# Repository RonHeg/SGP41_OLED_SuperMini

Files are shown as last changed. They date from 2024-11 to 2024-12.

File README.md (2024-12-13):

The Evs-2 SGP41 OLED SuperMini is a small PCB from RJ Hegler Technologies, LLC containing Temperature, Humidity, Pressure, VOC and NOx sensors designed to connect to the ESP32C3 SuperMini microcontroller. The PCB is also configurable to easily attach to a XIAO microcontroller or, 
with jumper wires, you could attach it to other processors.

The sensors are: Sensirion AG SHT-40-AD1B Temperature and Humidity. Sensirion AG SGP41-D-R4 NOx and VOC. TDK ICP-10111 Barometric pressure and temperature. The PCB uses its hosts 3.3v supply (~11mA with the pre-loaded software) and communicates via I2C.

EVs-2_SGP41_VOC.ino sends data thru the serial port at a baud rate of 115,200 and also displays 4 lines on a OLED display (if you are using a different display, please verify pinout, some OLED displays have Vcc and GND reversed).
The OLED display reads:

	SGP41 VOC Sensor
	78.23F, RH 48.00%
	NOx = 1, VOC = 94
	28.97inHg
 
(Numbers in the data are an example, your readings should be the actual for your conditions)

Example of data sent through the serial port is:

------------------------------

SHT40

T: 26.32        RH: 28.41

Tticks: 26704   RHticks: 18016

SGP41

compensationRh: 18016   compensationT: 26704

raw VOC Index: 28689    raw NOx Index: 0

VOC Index: 0    NOx Index: 0

ICP-10111

Temperature: 27.38C

99919.05Pa      29.51inHg

Altitude: 132.09m

------------------------------

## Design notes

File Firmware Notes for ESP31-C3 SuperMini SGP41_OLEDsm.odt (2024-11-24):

Firmware Notes

RJ Hegler Technologies, LLC

Project: SGP41_OLED_SuperMini

Processor: ESP32-C3 SuperMini or Seeed Studio XIAO ESP32C3 depending on resistor settings

Board: Nologo ESP32C3 Super Mini

Development Platform: Arduino 2.3.3

PC: Main

Path: C:\Users\Ron\Documents\Arduino\STM32G0Blink\Evs-2_SGP41_VOC\Evs_SGP41_VOC.ino

#include <Arduino.h>

/*

* I2C-Generator: 0.3.0

* Yaml Version: 0.1.0

* Template Version: 0.7.0-62-g3d691f9

*/

/*

*

* Portions Copyright (c) 2021, Sensirion AG

* All rights reserved.

*

* Redistribution and use in source and binary forms, with or without

* modification, are permitted provided that the following conditions are met:

*

* * Redistributions of source code must retain the above copyright notice, this

* list of conditions and the following disclaimer.

*

* * Redistributions in binary form must reproduce the above copyright notice,

* this list of conditions and the following disclaimer in the documentation

* and/or other materials provided with the distribution.

*

* * Neither the name of Sensirion AG nor the names of its

* contributors may be used to endorse or promote products derived from

* this software without specific prior written permission.

*

* THIS SOFTWARE IS PROVIDED BY THE COPYRIGHT HOLDERS AND CONTRIBUTORS "AS IS"

* AND ANY EXPRESS OR IMPLIED WARRANTIES, INCLUDING, BUT NOT LIMITED TO, THE

* IMPLIED WARRANTIES OF MERCHANTABILITY AND FITNESS FOR A PARTICULAR PURPOSE

* ARE DISCLAIMED. IN NO EVENT SHALL THE COPYRIGHT HOLDER OR CONTRIBUTORS BE

* LIABLE FOR ANY DIRECT, INDIRECT, INCIDENTAL, SPECIAL, EXEMPLARY, OR

* CONSEQUENTIAL DAMAGES (INCLUDING, BUT NOT LIMITED TO, PROCUREMENT OF

* SUBSTITUTE GOODS OR SERVICES; LOSS OF USE, DATA, OR PROFITS; OR BUSINESS

* INTERRUPTION) HOWEVER CAUSED AND ON ANY THEORY OF LIABILITY, WHETHER IN

* CONTRACT, STRICT LIABILITY, OR TORT (INCLUDING NEGLIGENCE OR OTHERWISE)

* ARISING IN ANY WAY OUT OF THE USE OF THIS SOFTWARE, EVEN IF ADVISED OF THE

* POSSIBILITY OF SUCH DAMAGE.

* Portions Copyright (c) 2024, RJ Hegler Technologies, LLC

* Other Copyright information can be found in the .h files listed below

*

* 11/21/24 RJH

*/

#include <Wire.h>

#include <NOxGasIndexAlgorithm.h>

#include <SensirionI2CSgp41.h>

#include <SensirionI2cSht4x.h>

#include <VOCGasIndexAlgorithm.h>

#include <DFRobot_ICP10111.h>

#include <U8g2lib.h>

U8G2_SSD1306_128X64_NONAME_F_HW_I2C u8g2(U8G2_R0, /* reset=*/ U8X8_PIN_NONE); //U8g2lib has 'drivers' for quite a few other displays

SensirionI2cSht4x sht4x; // original code had: SensirionI2CSht4x (capitol C)

SensirionI2CSgp41 sgp41;

DFRobot_ICP10111 icp;

VOCGasIndexAlgorithm voc_algorithm;

NOxGasIndexAlgorithm nox_algorithm;

// Time in seconds needed for NOx conditioning

// WARNING: To avoid damage to the sensing material the conditioning must not

// exceed 10s!

uint16_t conditioning_s = 10;

char errorMessage[64];

void setup() {

Serial.begin(115200);

Wire.begin();

sht4x.begin(Wire, 0x44); //original code did not have the I2C address

sgp41.begin(Wire);

u8g2.begin();

u8g2.enableUTF8Print();

u8g2.clearBuffer(); // clear the internal memory

u8g2.setFont(u8g2_font_7x14B_tf);

//u8g2.setFont(u8g2_font_t0_11_tf);

u8g2.drawStr(0,12, "SGP41 VOC Sensor");

u8g2.drawStr(0,28, "Initializing...");

u8g2.sendBuffer(); // transfer internal memory to the display

delay(1000);

int32_t index_offset;

int32_t learning_time_offset_hours;

int32_t learning_time_gain_hours;

int32_t gating_max_duration_minutes;

int32_t std_initial;

int32_t gain_factor;

voc_algorithm.get_tuning_parameters(

index_offset, learning_time_offset_hours, learning_time_gain_hours,

gating_max_duration_minutes, std_initial, gain_factor);

Serial.println("\nVOC Gas Index Algorithm parameters");

Serial.print("Index offset:\t");

Serial.println(index_offset);

Serial.print("Learing time offset hours:\t");

Serial.println(learning_time_offset_hours);

Serial.print("Learing time gain hours:\t");

Serial.println(learning_time_gain_hours);

Serial.print("Gating max duration minutes:\t");

Serial.println(gating_max_duration_minutes);

Serial.print("Std inital:\t");

Serial.println(std_initial);

Serial.print("Gain factor:\t");

Serial.println(gain_factor);

nox_algorithm.get_tuning_parameters(

index_offset, learning_time_offset_hours, learning_time_gain_hours,

gating_max_duration_minutes, std_initial, gain_factor);

Serial.println("\nNOx Gas Index Algorithm parameters");

Serial.print("Index offset:\t");

Serial.println(index_offset);

Serial.print("Learing time offset hours:\t");

Serial.println(learning_time_offset_hours);

Serial.print("Gating max duration minutes:\t");

Serial.println(gating_max_duration_minutes);

Serial.print("Gain factor:\t");

Serial.println(gain_factor);

Serial.println("");

// Initialize ICP-10111 - barometric pressure sensor

if (icp.begin() != 0) {

Serial.println("Failed to initialize ICP-10111 sensor");

}

else{

Serial.println("ICP-10111 sensor found!");

/**

* @brief Set work mode

* |------------------|--------------|-------------------|----------------------|

* | api | mode |Conversion Time(ms)|Pressure RMS Noise(Pa)|

* |icp.eLowPower | Low Power | 1.8 | 3.2 |

* |icp.eNormal | Normal | 6.3 | 1.6 |

* |icp.eLowNoise | Low Noise | 23.8 | 0.8 |

* |icp.eUltraLowNoise| Ultra-low Noise | 94.5 | 0.4 |

*/

icp.setWorkPattern(icp.eNormal);

}

}

void loop() {

uint16_t error;

float humidity = 0; // %RH

float temperature = 0; // degreeC

uint16_t temperatureTicks;

uint16_t humidityTicks;

uint16_t srawVoc = 0;

uint16_t srawNox = 0;

uint16_t defaultCompensationRh = 0x8000; // in ticks as defined by SGP41

uint16_t defaultCompensationT = 0x6666; // in ticks as defined by SGP41

uint16_t compensationRh = 0; // in ticks as defined by SGP41

uint16_t compensationT = 0; // in ticks as defined by SGP41

u8g2.clearBuffer(); // clear the internal memory

u8g2.setFont(u8g2_font_7x14B_tf);

//u8g2.setFont(u8g2_font_t0_11_tf);

u8g2.drawStr(0,12, "SGP41 VOC Sensor");

// 1. Sleep: Measure every second (1Hz), as defined by the Gas Index

// Algorithm

// prerequisite

delay(1000);

// 2. Measure temperature and humidity for SGP internal compensation

error = sht4x.measureHighPrecision(temperature, humidity);

error = sht4x.measureHighPrecisionTicks(temperatureTicks, humidityTicks);

//temperature = 175 * temperatureTicks/65535-45;

//humidity = 125 * humidityTicks/65535-6;

if (error) {

Serial.print(

"SHT4x - Error trying to execute measureHighPrecision(): ");

errorToString(error, errorMessage, 256);

Serial.println(errorMessage);

Serial.println("Fallback to use default values for humidity and "

"temperature compensation for SGP41");

compensationRh = defaultCompensationRh;

compensationT = defaultCompensationT;

} else {

compensationRh = humidityTicks; // compensationRh for SGP41

compensationT = temperatureTicks; // compensationT for SGP41

Serial.println("SHT40");

Serial.print("T: ");

Serial.print(temperature);

Serial.print("\t");

Serial.print("RH: ");

Serial.println(humidity);

Serial.print("Tticks: ");

Serial.print(temperatureTicks);

Serial.print("\t");

Serial.print("RHticks: ");

Serial.println(humidityTicks);

Serial.println("");

float temp = (temperature * 9/5) + 32; //must keep temperature in ticks for signal conditioning

u8g2.setCursor(0,28);

u8g2.print(String(temp) + "°F, RH " + String(humidity) + "%");

// convert temperature and humidity to ticks as defined by SGP41

// interface

// NOTE: in case you read RH and T raw signals check out the

// ticks specification in the datasheet, as they can be different for

// different sensors

//compensationT = static_cast<uint16_t>((temperature + 45) * 65535 / 175);

//compensationRh = static_cast<uint16_t>(humidity + 6 * 65535 / 125);

}

// 3. Measure SGP4x signals

if (conditioning_s > 0) {

// During NOx conditioning (10s) SRAW NOx will remain 0

error = sgp41.executeConditioning(compensationRh, compensationT, srawVoc);

conditioning_s--;

} else {

error = sgp41.measureRawSignals(compensationRh, compensationT, srawVoc, srawNox);

}

// 4. Process raw signals by Gas Index Algorithm to get the VOC and NOx

// index values

if (error) {

Serial.print("SGP41 - Error trying to execute measureRawSignals(): ");

errorToString(error, errorMessage, 256);

Serial.println(errorMessage);

} else {

Serial.println("SGP41");

Serial.print("compensationRh: ");

Serial.print(compensationRh);

Serial.print("\t");

Serial.print("compensationT: ");

Serial.println(compensationT);

Serial.print("raw VOC Index: ");

Serial.print(srawVoc);

Serial.print("\t");

Serial.print("raw NOx Index: ");

Serial.println(srawNox);

int32_t voc_index = voc_algorithm.process(srawVoc);

int32_t nox_index = nox_algorithm.process(srawNox);

Serial.print("VOC Index: ");

Serial.print(voc_index);

Serial.print("\t");

Serial.print("NOx Index: ");

Serial.println(nox_index);

Serial.println("");

u8g2.setCursor(0,43);

u8g2.print("NOx = " + String(nox_index));

u8g2.print(", VOC = " + String(voc_index));

}

// Read ICP-10111 data

Serial.println("ICP-10111 ");

Serial.print("Temperature: ");

Serial.print(icp.getTemperature());

Serial.println("C");

float ap = icp.getAirPressure();

Serial.print(String(ap));

Serial.print("Pa");

Serial.print(" \t");

float Hg = ap/3386;

Serial.print(String(Hg));

Serial.println("inHg");

Serial.print("Altitude: ");

float alt = icp.getElevation();

Serial.print(String(alt));

Serial.println("m");

Serial.println("------------------------------");

u8g2.setCursor(0,58);

u8g2.print(String(Hg) + "inHg");

u8g2.sendBuffer(); // transfer internal memory to the display

delay(2000); // Wait for 2 seconds before next reading

}

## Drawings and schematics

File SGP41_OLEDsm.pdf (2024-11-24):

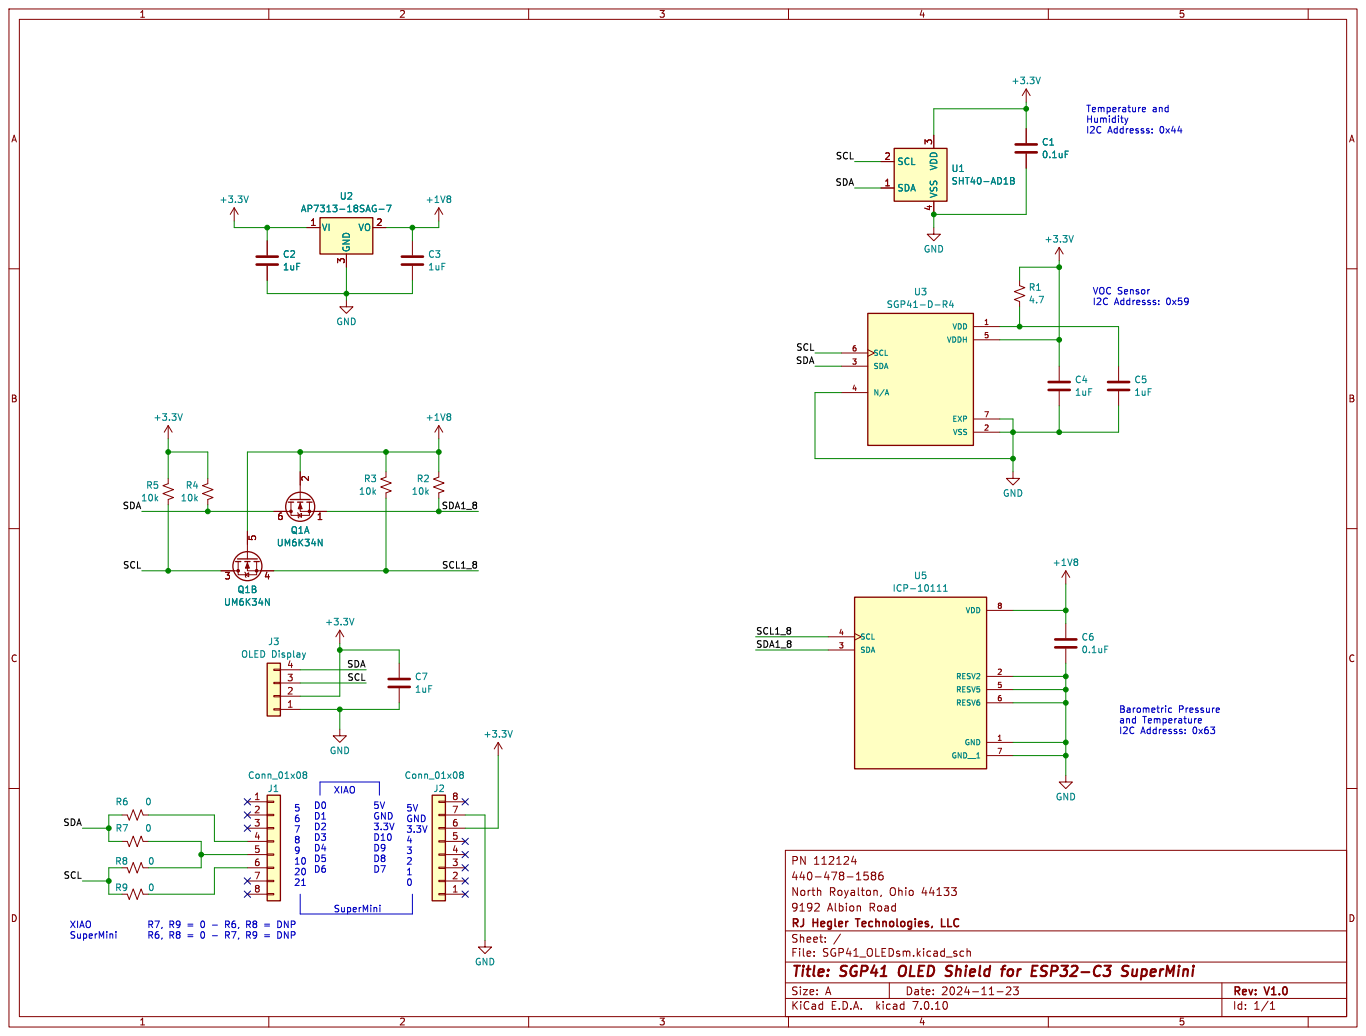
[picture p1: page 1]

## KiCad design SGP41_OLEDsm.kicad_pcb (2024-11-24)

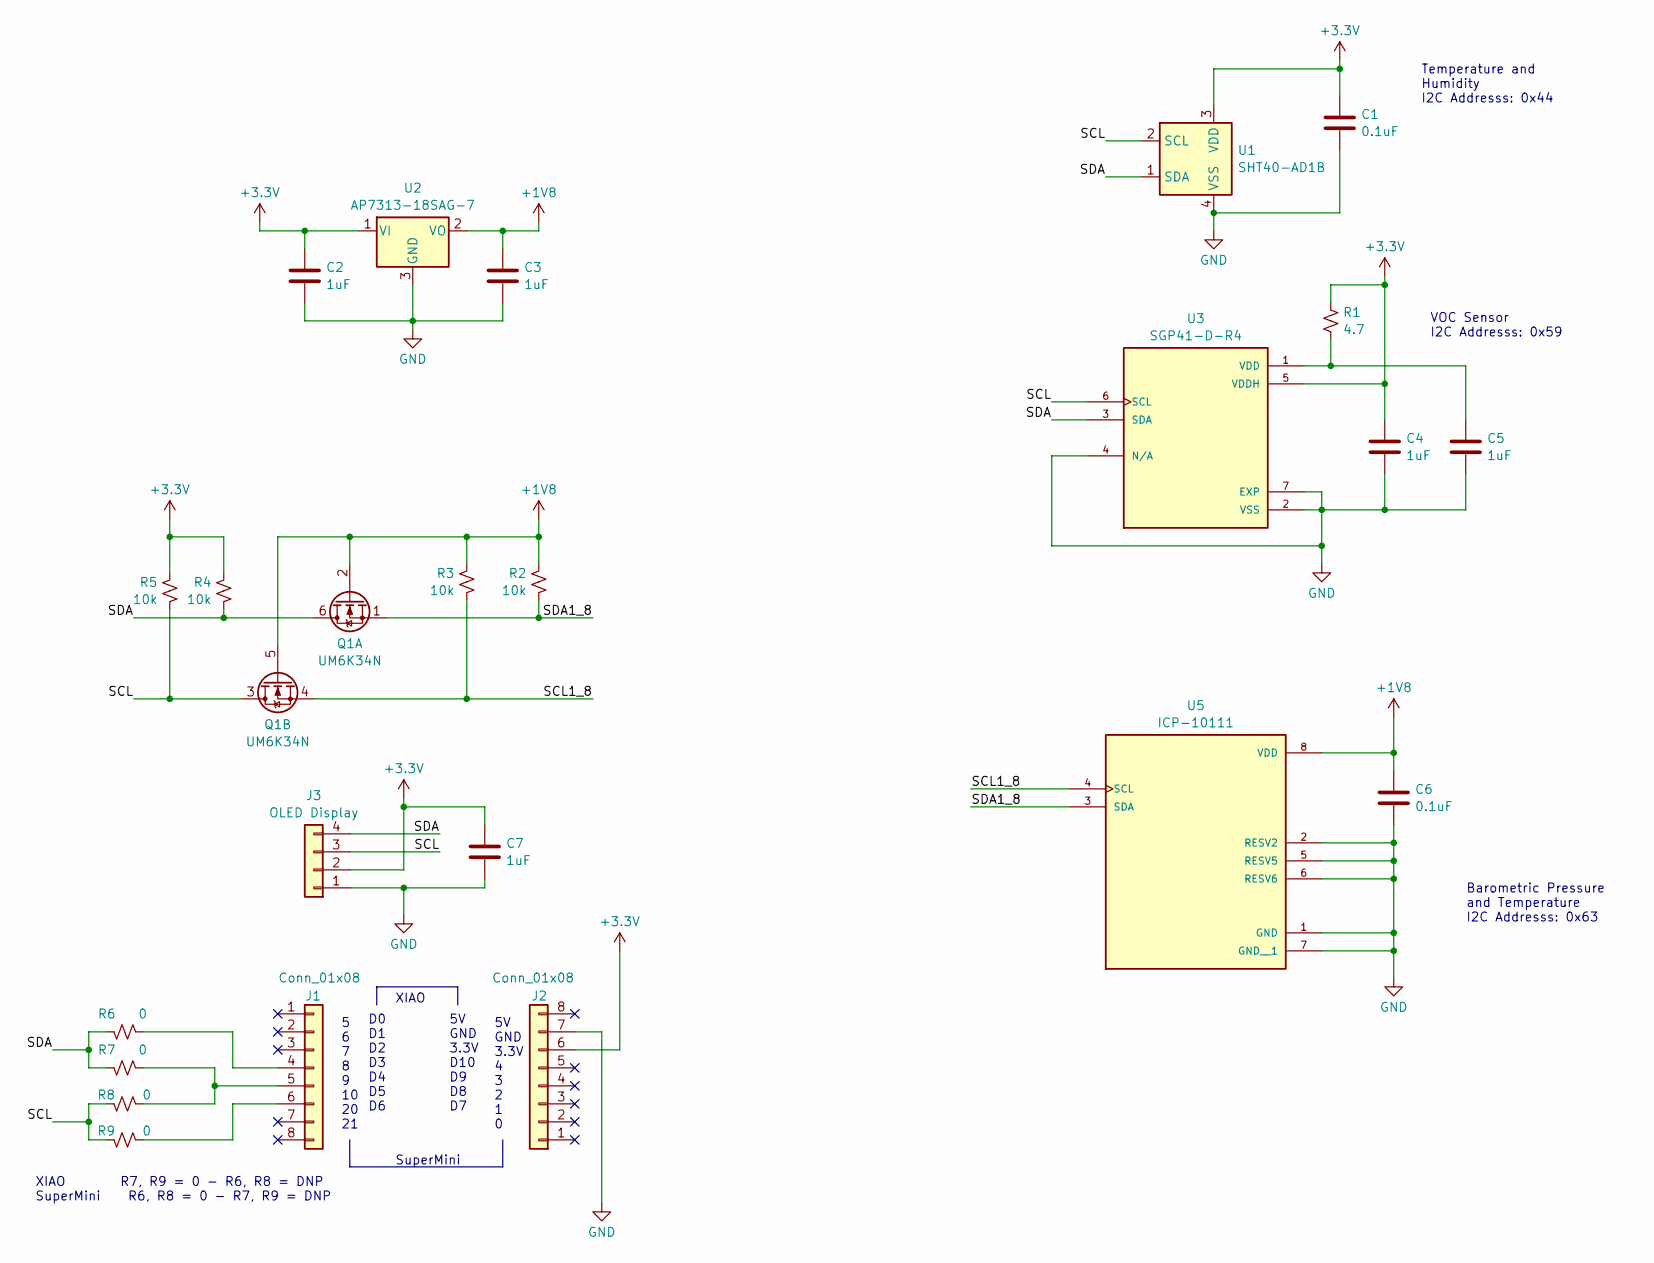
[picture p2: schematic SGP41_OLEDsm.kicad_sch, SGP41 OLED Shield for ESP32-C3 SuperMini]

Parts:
C1, C6: 0.1uF; C_0603_1608Metric; Manufacturer_Part_Number GCM188R71H104JA57D; JLC Pricing 0.0286
C2, C3, C4, C5, C7: 1uF; C_0603_1608Metric; Manufacturer_Part_Number C1608X5R1A105KT000E; JLC Pricing 0.0143
J1, J2: Conn_01x08; PinSocket_1x08_P2.54mm_Vertical; JLC Pricing 0.42913
J3: OLED Display; PinSocket_1x04_P2.54mm_Vertical
Q1: UM6K34N; SOT-363_SC-70-6; Manufacturer_Part_Number UM6K34N; JLC Pricing 0.0924
R1: 4.7; R_0603_1608Metric; Manufacturer_Part_Number CRCW06034R70FKEAHP; JLC Pricing 0.0857
R2, R3, R4, R5: 10k; R_0603_1608Metric; Manufacturer_Part_Number MCT06030C1002FP500; JLC Pricing 0.0157
R6, R7, R8, R9: 0; R_0603_1608Metric; Manufacturer_Part_Number CRCW06030000Z0EA; JLC Pricing .008
U1: SHT40-AD1B; Sensirion_DFN-4_1.5x1.5mm_P0.8mm_SHT4x_NoCentralPad; Manufacturer_Part_Number SHT40-AD1B-R3; JLC Pricing 1.6267
U2: AP7313-18SAG-7; SOT-23; Manufacturer_Part_Number AP7313-18SAG-7; JLC Pricing 0.1225
U3: SGP41-D-R4; XCDR_SGP40-D-R4[1]; PARTREV 1.2; JLC Pricing 6.0535
U5: ICP-10111; PSON65P250X200X100-8N; PARTREV 1.0; JLC Pricing 1.0804

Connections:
+1V8: C3.1, C6.1, Q1.2 (G), Q1.5 (G), R2.1, R3.1, U2.2 (VO), U5.8 (VDD)
+3.3V: C1.1, C2.1, C4.1, C7.1, J2.6, J3.2, R1.1, R4.1, R5.1, U1.3 (VDD), U2.1 (VI), U3.5 (VDDH)
/SCL: J3.3, Q1.3 (D), R5.2, R8.1, R9.1, U1.2 (SCL), U3.6 (SCL)
/SCL1_8: Q1.4 (S), R3.2, U5.4 (SCL)
/SDA: J3.4, Q1.6 (D), R4.2, R6.1, R7.1, U1.1 (SDA), U3.3 (SDA)
/SDA1_8: Q1.1 (S), R2.2, U5.3 (SDA)
GND: C1.2, C2.2, C3.2, C4.2, C5.2, C6.2, C7.2, J2.7, J3.1, U1.4 (VSS), U2.3 (GND), U3.2 (VSS), U3.4 (N/A), U3.7 (EXP), U5.1 (GND), U5.2 (RESV2), U5.5 (RESV5), U5.6 (RESV6), U5.7 (GND__1)
unnamed: J1.4, R6.2
unnamed: J1.5, R7.2, R8.2
unnamed: J1.6, R9.2
unnamed: C5.1, R1.2, U3.1 (VDD)

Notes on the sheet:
XIAO R7, R9 = 0 - R6, R8 = DNP SuperMini R6, R8 = 0 - R7, R9 = DNP
5V GND 3.3V D10 D9 D8 D7
D0 D1 D2 D3 D4 D5 D6
XIAO
Barometric Pressure and Temperature I2C Addresss: 0x63
SuperMini
5V GND 3.3V 4 3 2 1 0
5 6 7 8 9 10 20 21
VOC Sensor I2C Addresss: 0x59
Temperature and Humidity I2C Addresss: 0x44

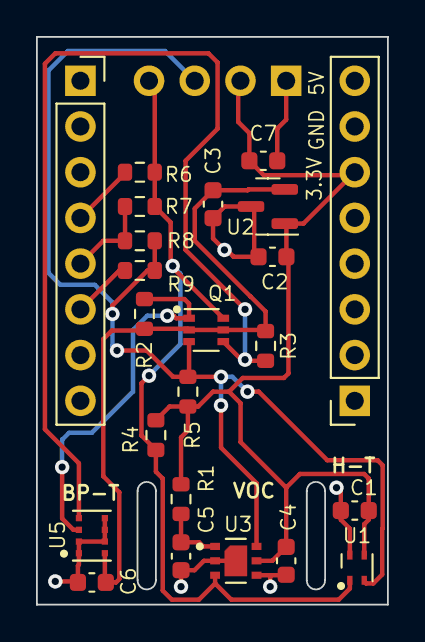
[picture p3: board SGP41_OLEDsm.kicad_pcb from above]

Board: 2 copper layers, 19.5 x 31.5 mm, 24 parts (1 on the bottom side), 11 nets.

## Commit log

2024-11-24 Initialization
    Initial files
    [SGP41_OLEDsm.kicad_pcb, SGP41_OLEDsm.kicad_sch]
2024-12-19 ino file was missing
    [Evs-2_SGP41_VOC.ino]
